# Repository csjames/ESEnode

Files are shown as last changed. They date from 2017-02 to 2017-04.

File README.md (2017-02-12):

# ESEnode

* 868 Mhz radio and LoRa development board
* MBED Compatible
* RGB LED
* Full Bill of Materials

# Radio Modules Compatible

## RFM69HW (868 FSK)
RFM69
## RFM95 (LoRa)
RFM95

### Designed by Joshua Curry and James Adams

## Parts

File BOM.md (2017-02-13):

# Bill of Materials

| Part 	| Price 	| Quantity |
|---	|---	| ---|
| **[LPC11U68](http://onecall.farnell.com/nxp/lpc11u68jbd48e/mcu-32bit-cortex-m0-50mhz-lqfp/dp/2433462)** 	| 2.61  	| 1|
| **[RFM69HW](http://onecall.farnell.com/hoperf/rfm69hw-868s2/transceiver-20dbm-116dbm-868mhz/dp/RF00489)** 	| 6.67  	| 1|
| **[RFM95W](http://onecall.farnell.com/hoperf/rfm95w-868s2/lora-transceiver-module-20dbm/dp/RF00490)** | 13.56 | 1|
| **[RGB LED PLCC-4](http://onecall.farnell.com/broadcom-limited/asmb-mtb1-0a3a2/led-hb-rgb-0-09w-plcc-4/dp/2401106)** 	| 0.12  	| 1|
| **[10Ω 0603](http://onecall.farnell.com/multicomp/mc0063w0603110r/res-thick-film-10r-1-0-063w-0603/dp/9330429)**|0.10 (x100)|2|
| **[10uF 0603](http://onecall.farnell.com/multicomp/mcca000180/mlcc-0603-y5v-25v-1uf/dp/CA06409)**|1.00 (x100)|1| 	| 	| 1|
| **[Micro USB A/B Female](http://onecall.farnell.com/molex/47589-0001/micro-usb-2-0-type-ab-receptacle/dp/1568023)**|0.32|1|
| **[Antenna](https://www.aliexpress.com/item/GSM-868M-900M-915MHz-antenna-2dbi-SMA-male-connector-5cm-long-RC-Receive-transmit-aerial-2/32511895558.html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,searchweb201602_4_10065_10068_10000074_10000032_119_10060_10062_10056_10055_10000062_10054_301_10059_10099_10000013_10103_10102_10000016_10096_10000056_10000059_10052_10053_10107_10050_10106_10051_10000097_10000094_10000053_10000007_10000050_10084_10000100_10083_10000047_10080_10082_10081_10110_10111_10112_10113_10114_10115_10037_10000041_10000044_10078_10079_10077_10000038_10073_10000035_10122_10121,searchweb201603_2,afswitch_2,ppcSwitch_5,single_sort_2_default&btsid=2f6a1d46-ff44-4a59-8876-1fd172cdf7d6)** | 2.13 | 1 |
| **[SMA Board Connector](http://onecall.farnell.com/lprs/sma-ra-connector/connector-sma-r-angled/dp/2096224)**|1.00|1|
| **[25MHz Resonator](http://www.digikey.co.uk/product-detail/en/abracon-llc/AWSCR-25.00CV-T/535-10013-1-ND/2001636)**|0.45|1|
| **TOTAL** | **14.28/20.48**(RFM69/95) | - |

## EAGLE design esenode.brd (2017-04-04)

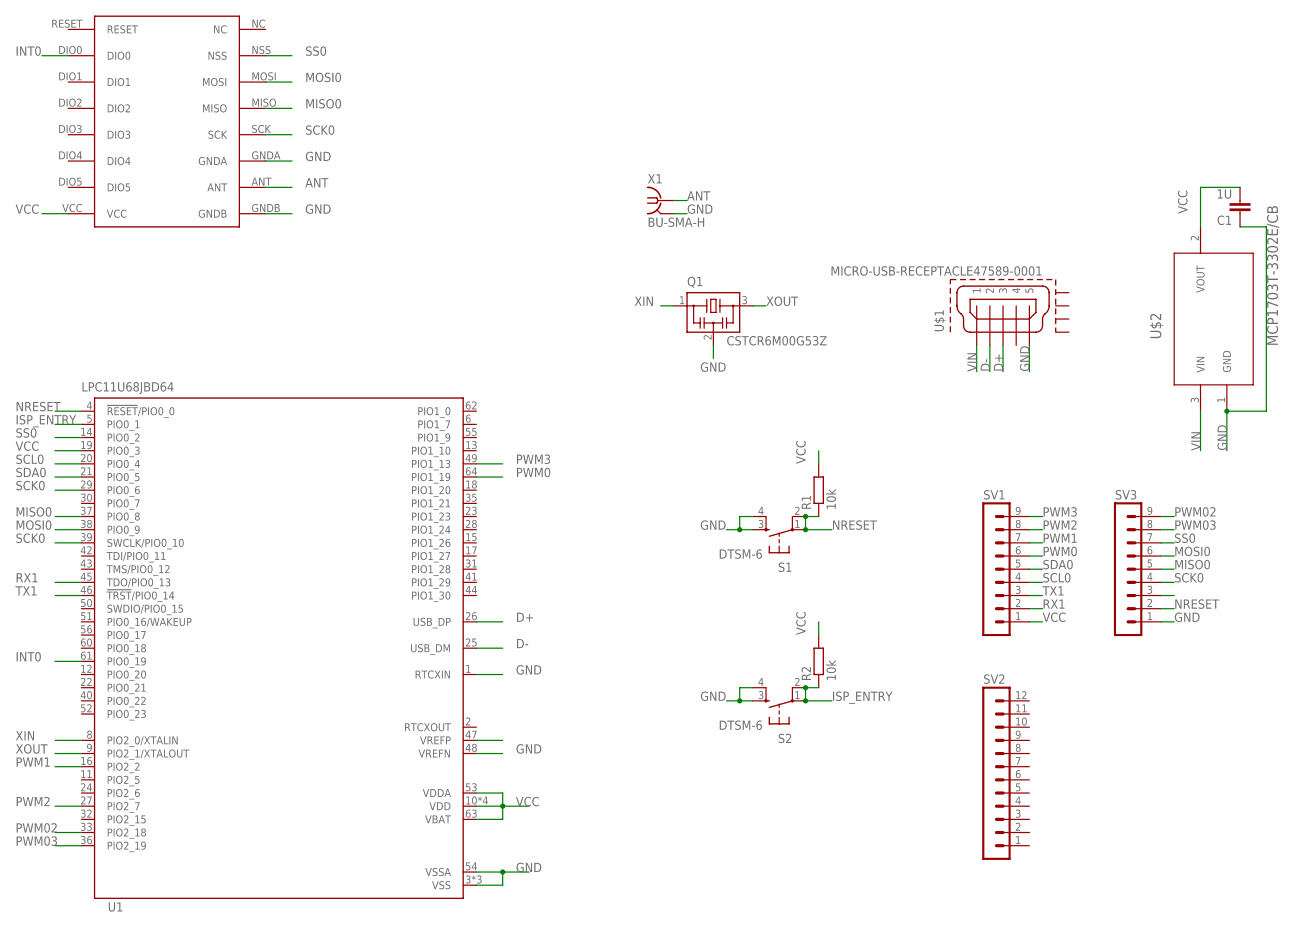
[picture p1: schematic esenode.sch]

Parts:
C1: 1U; C0805
Q1: CSTCR6M00G53Z; CSTCR6M
R1, R2: 10k; M0805
S1, S2: DTSM-6
SV1, SV3: MA09-1
SV2: MA12-1
U1: LPC11U68JBD64; SOT314-2
U$1: MICRO-USB-RECEPTACLE47589-0001; 47589-0001
U$2: MCP1703T-3302E/CB; SOT95P300X145-3N
U$3: RFM69HW; RFM
X1: BU-SMA-H

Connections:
ANT: U$3.ANT, X1.1
D+: U1.26 (USB_DP), U$1.3
D-: U1.25 (USB_DM), U$1.2
GND: C1.1, Q1.2, S1.3, S1.4, S2.3, S2.4, SV3.1, U1.1 (RTCXIN), U1.3 (VSS), U1.7 (VSS), U1.48 (VREFN), U1.54 (VSSA), U1.57 (VSS), U$1.5, U$2.1 (GND), U$3.GNDA, U$3.GNDB, X1.2, X1.3 (2), X1.4 (2), X1.5 (2)
INT0: U1.61 (PIO0_19), U$3.DIO0
ISP_ENTRY: R2.1, S2.1, S2.2, U1.5 (PIO0_1)
MISO0: SV3.5, U1.37 (PIO0_8), U$3.MISO
MOSI0: SV3.6, U1.38 (PIO0_9), U$3.MOSI
NRESET: R1.1, S1.1, S1.2, SV3.2, U1.4 (!RESET!/PIO0_0)
PWM0: SV1.6, U1.64 (PIO1_19)
PWM1: SV1.7, U1.16 (PIO2_2)
PWM2: SV1.8, U1.27 (PIO2_7)
PWM02: SV3.9, U1.33 (PIO2_18)
PWM3: SV1.9, U1.49 (PIO1_13)
PWM03: SV3.8, U1.36 (PIO2_19)
RX1: SV1.2, U1.45 (TDO/PIO0_13)
SCK0: SV3.4, U1.29 (PIO0_6), U1.39 (SWCLK/PIO0_10), U$3.SCK
SCL0: SV1.4, U1.20 (PIO0_4)
SDA0: SV1.5, U1.21 (PIO0_5)
SS0: SV3.7, U1.14 (PIO0_2), U$3.NSS
TX1: SV1.3, U1.46 (!TRST!/PIO0_14)
VCC: C1.2, R1.2, R2.2, SV1.1, U1.10 (VDD), U1.19 (PIO0_3), U1.34 (VDD), U1.53 (VDDA), U1.58 (VDD), U1.59 (VDD), U1.63 (VBAT), U$2.2 (VOUT), U$3.VCC
VIN: U$1.1, U$2.3 (VIN)
XIN: Q1.1, U1.8 (PIO2_0/XTALIN)
XOUT: Q1.3, U1.9 (PIO2_1/XTALOUT)

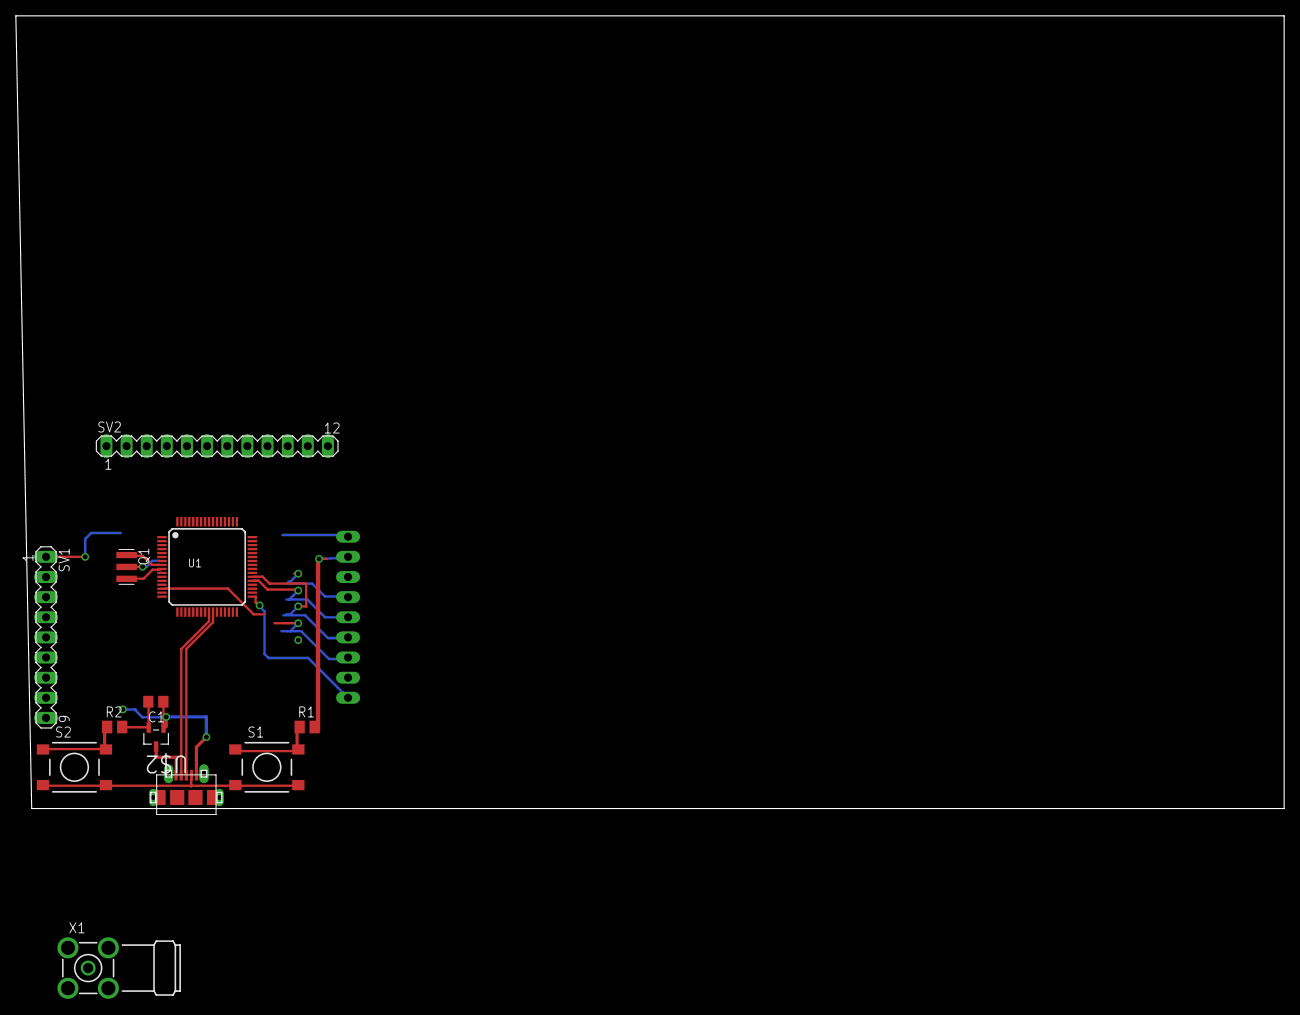
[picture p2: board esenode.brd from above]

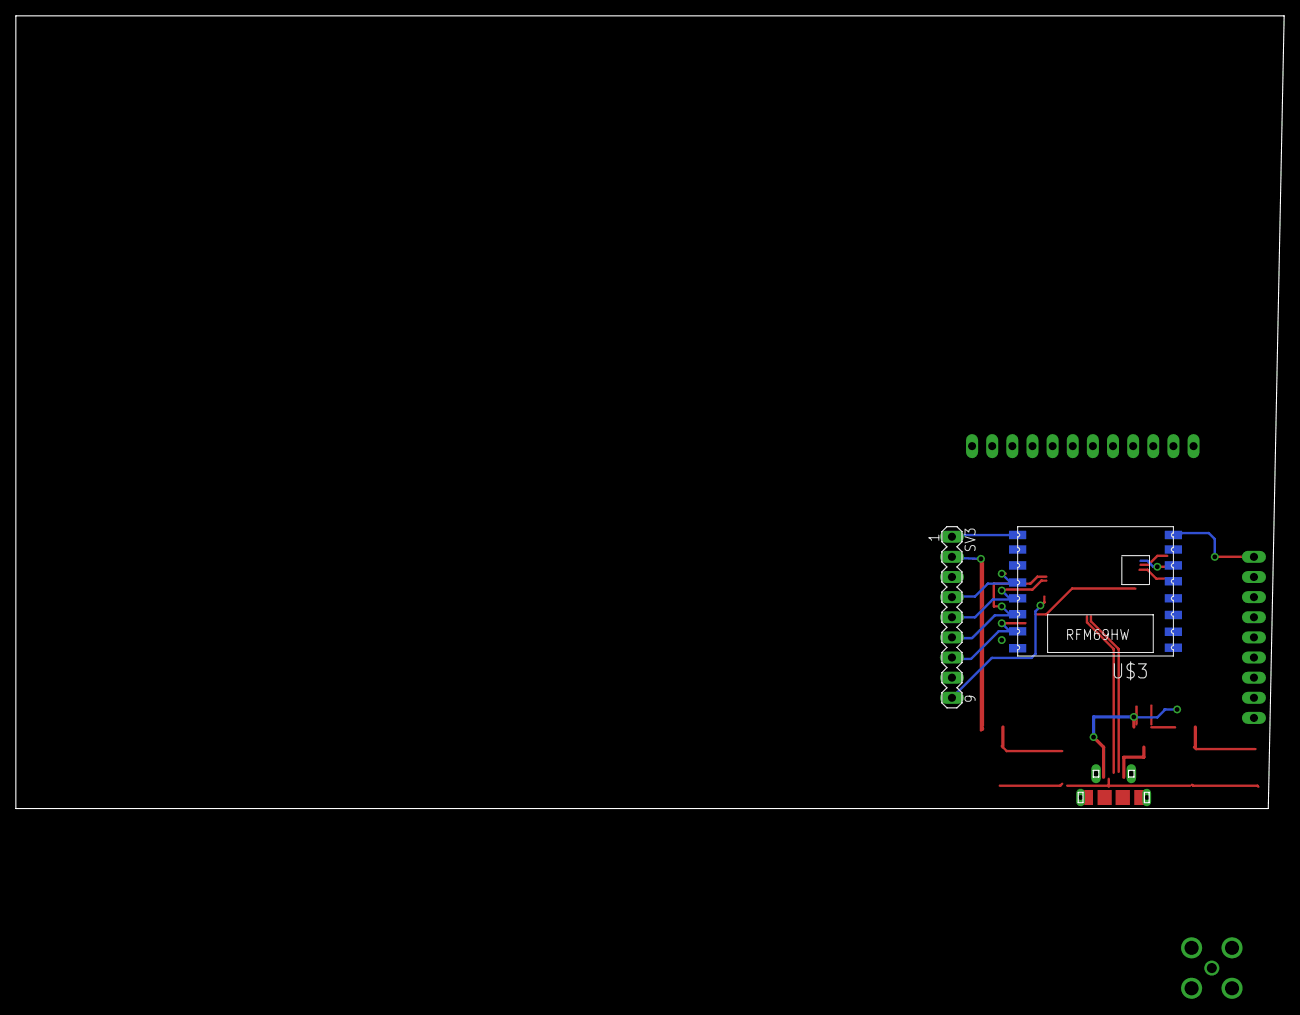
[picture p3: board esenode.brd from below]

Board: 2 copper layers, 160.0 x 100.0 mm, 14 parts (2 on the bottom side), 25 nets.

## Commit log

2017-02-11 added libraries and board draft
    [esenode.brd, esenode.sch]
2017-04-04 #challenge, then connect gpio to top bar and see if still possible lol
    [esenode.brd, esenode.sch]
2017-04-04 added antenna
    [esenode.brd, esenode.sch]

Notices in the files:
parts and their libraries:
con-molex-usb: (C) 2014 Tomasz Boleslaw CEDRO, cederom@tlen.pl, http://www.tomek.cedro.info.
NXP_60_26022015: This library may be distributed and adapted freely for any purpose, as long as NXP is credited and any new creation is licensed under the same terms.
